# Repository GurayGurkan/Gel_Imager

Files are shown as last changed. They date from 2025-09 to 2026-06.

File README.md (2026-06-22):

# Open Science Multi-function Gel Imager
*An Open-Hardware Agorose Gel and Chemiluminicance Imaging System Based on Raspberry Pi 4B*

This repository involves:
  - **Mechanical Design Files**: FreeCAD drawingshousing of Incu-stream mechanical parts
  - **Electronics**: Circuit schematics and PCB layout files of Raspberrry Pi 4B shield and led control electronics.
  - **Software**: Involves Python codes for main control and user interface. 
  -

For suggestions and questions, please e-mail to ***guraygurkan@istanbul.edu.tr***

Cheers!

Guray Gurkan

* **Please cite this repo as:** 

(Under Review: submitted to Scientific Reports for review)

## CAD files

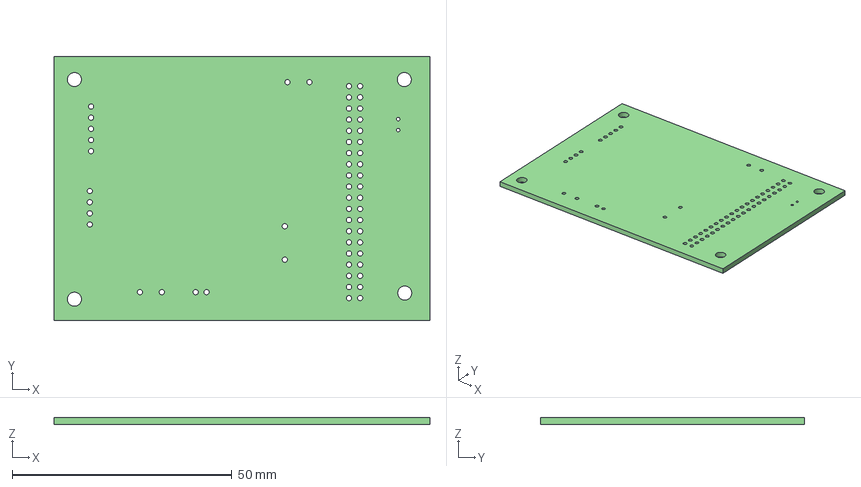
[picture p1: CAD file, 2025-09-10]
Hardware/Electronics/RaspShiled_ver3/RaspShiled_ver3.step
85.6 x 60.0 x 1.60 mm

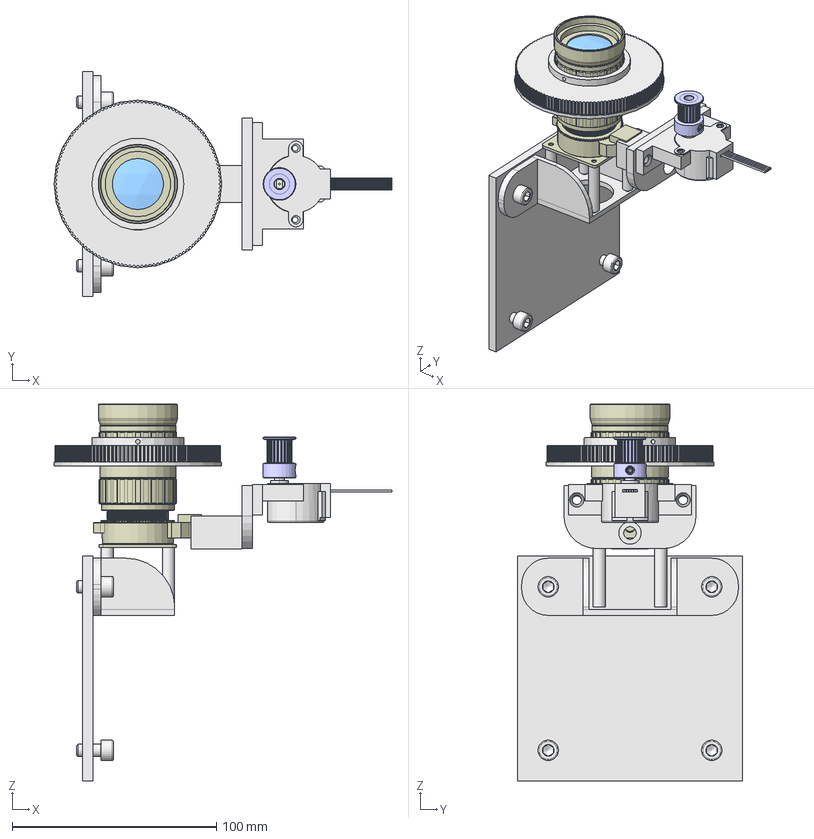
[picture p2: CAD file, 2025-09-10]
Hardware/Mechanical_Designs/Lens_Focus_Control_Design.FCStd
165.2 x 110.0 x 184.4 mm
PICAM HQ
PICAM HQ LENS
Motor
M4x0.7X5mm - flat-tip Set screw
M4x0.7X5mm - flat-tip Set screw001
SystemBracket
LensGear_128
_8byj_48_bracket001 (Solid)001
Distances
_DIN 912-M6x12
_DIN 912-M6x013
_DIN 912-M6x014
_DIN 912-M6x015

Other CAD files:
Hardware/Mechanical_Designs/CNC_Cut_Layer_Designs.FCStd

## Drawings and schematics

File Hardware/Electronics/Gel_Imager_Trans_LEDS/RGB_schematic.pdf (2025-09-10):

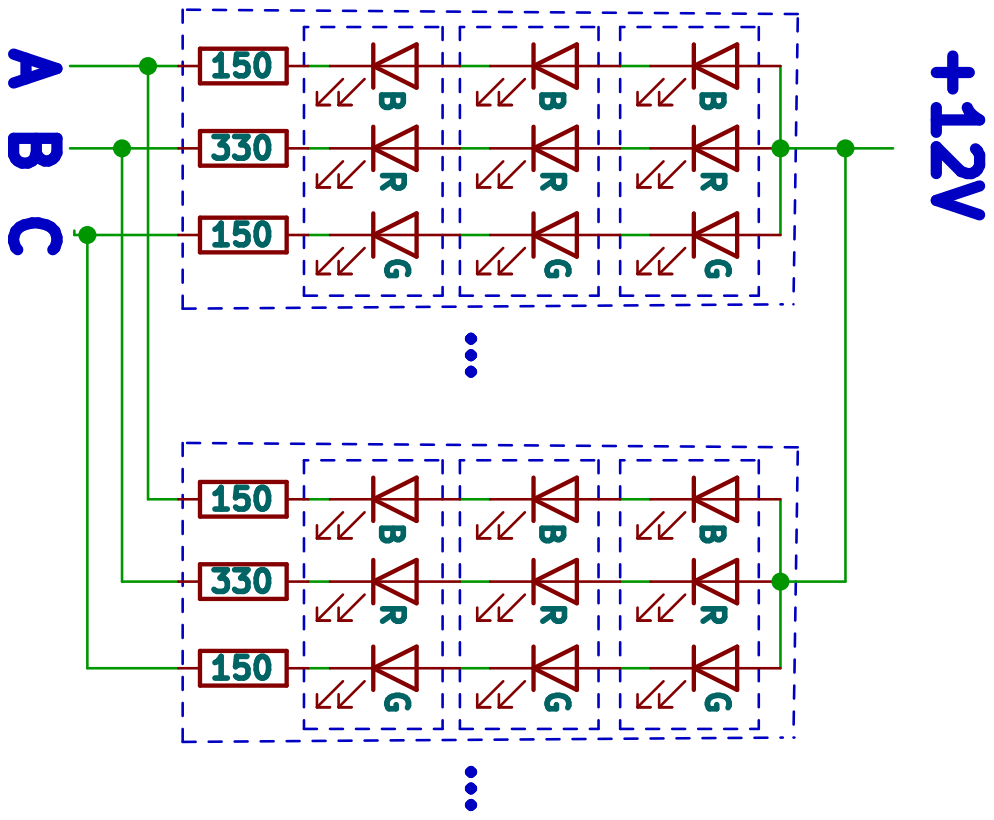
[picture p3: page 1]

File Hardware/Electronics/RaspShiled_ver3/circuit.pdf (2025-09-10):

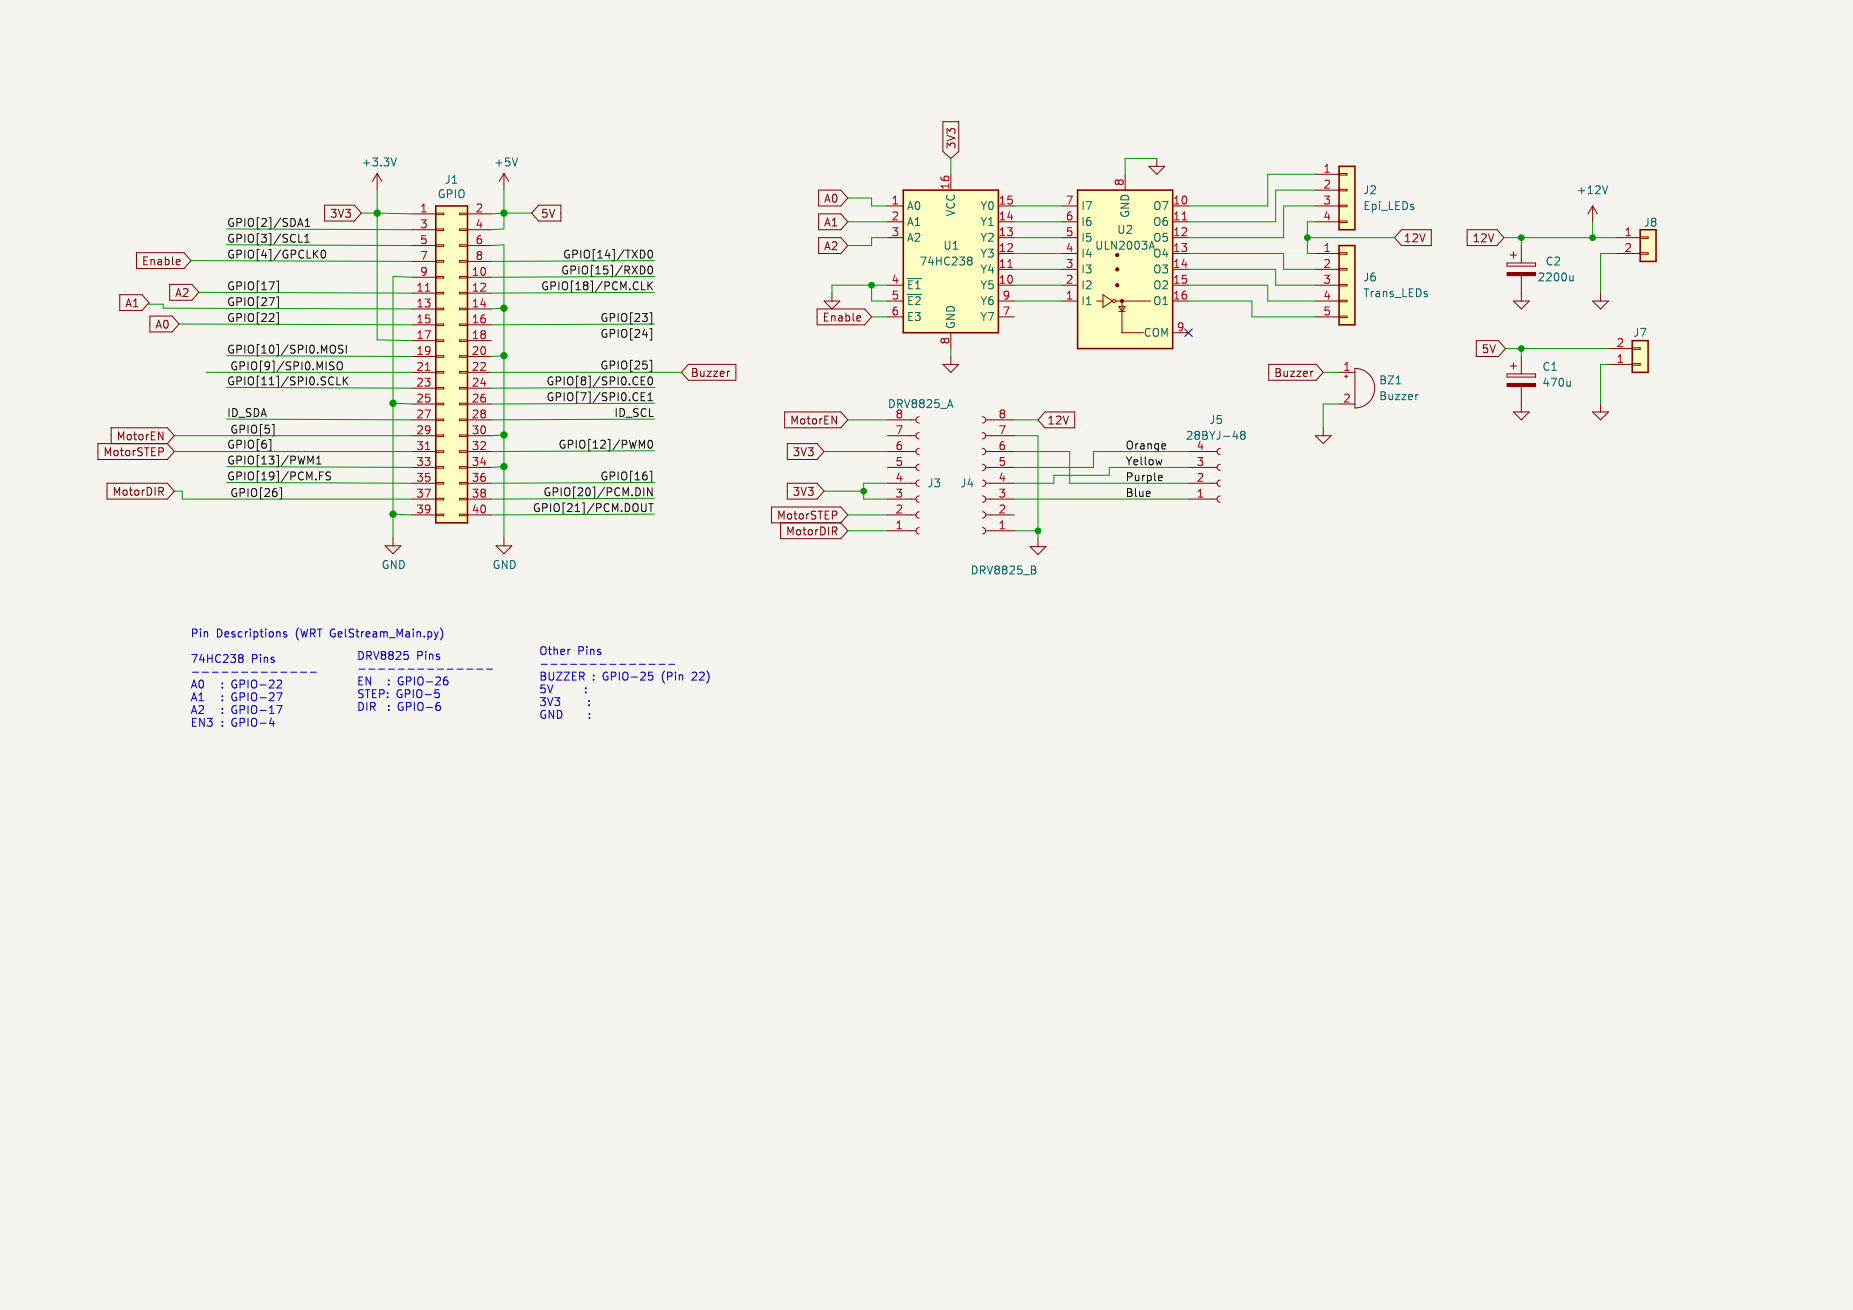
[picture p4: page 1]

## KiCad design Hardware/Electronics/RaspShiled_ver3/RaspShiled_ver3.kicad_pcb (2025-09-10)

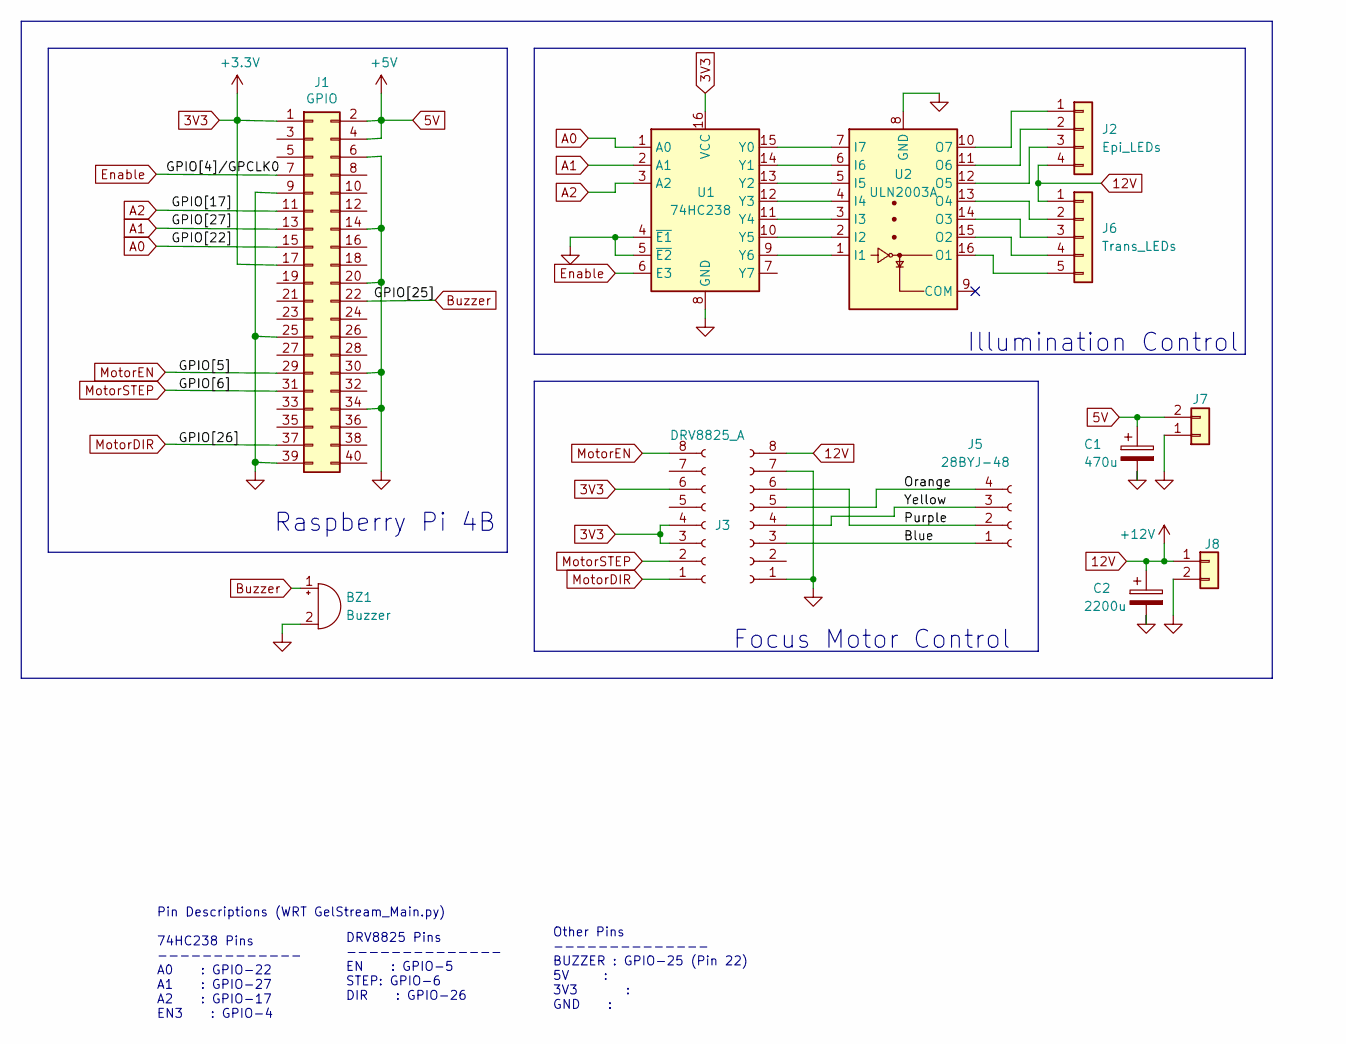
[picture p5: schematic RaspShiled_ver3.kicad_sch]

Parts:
BZ1: Buzzer; Buzzer_12x9.5RM7.6
C1: 470u; CP_Radial_D6.3mm_P2.50mm
C2: 2200u; CP_Radial_D6.3mm_P2.50mm
J1: GPIO; PinHeader_2x20_P2.54mm_Vertical
J2: Epi_LEDs; PinHeader_1x04_P2.54mm_Vertical
J3: DRV8825_A; PinSocket_1x08_P2.54mm_Vertical
J4: DRV8825_B; PinSocket_1x08_P2.54mm_Vertical
J5: 28BYJ-48; PinHeader_1x05_P2.54mm_Vertical
J6: Trans_LEDs; PinHeader_1x05_P2.54mm_Vertical
J7, J8: Conn_01x02; TerminalBlock_MetzConnect_Type011_RT05502HBWC_1x02_P5.00mm_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
U1: 74HC238; SOIC-16_3.9x9.9mm_P1.27mm
U2: ULN2003A; DIP-16_W7.62mm

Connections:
3V3: J1.1, J1.17, J3.3, J3.4, J3.6, U1.16 (VCC)
5V: C1.1, J1.2, J1.4, J7.2
12V: C2.1, J2.4, J4.8, J6.1, J8.1
/Blue: J4.3, J5.1
/GPIO[2]/SDA1: J1.3
/GPIO[3]/SCL1: J1.5
/GPIO[7]/SPI0.CE1: J1.26
/GPIO[8]/SPI0.CE0: J1.24
/GPIO[9]/SPI0.MISO: J1.21
/GPIO[10]/SPI0.MOSI: J1.19
/GPIO[11]/SPI0.SCLK: J1.23
/GPIO[12]/PWM0: J1.32
/GPIO[13]/PWM1: J1.33
/GPIO[14]/TXD0: J1.8
/GPIO[15]/RXD0: J1.10
/GPIO[16]: J1.36
/GPIO[18]/PCM.CLK: J1.12
/GPIO[19]/PCM.FS: J1.35
/GPIO[20]/PCM.DIN: J1.38
/GPIO[21]/PCM.DOUT: J1.40
/GPIO[23]: J1.16
/ID_SCL: J1.28
/ID_SDA: J1.27
/Orange: J4.5, J5.4
/Purple: J4.6, J5.2
/Yellow: J4.4, J5.3
A0: J1.15, U1.1 (A0)
A1: J1.13, U1.2 (A1)
A2: J1.11, U1.3 (A2)
Buzzer: BZ1.1 (-), J1.22
Enable: J1.7, U1.6 (E3)
Epi_Blue_EN: U1.15 (Y0), U2.7 (I7)
Epi_Green_EN: U1.13 (Y2), U2.5 (I5)
Epi_Red_EN: U1.14 (Y1), U2.6 (I6)
GND: BZ1.2 (+), C1.2, C2.2, J1.6, J1.9, J1.14, J1.20, J1.25, J1.30, J1.34, J1.39, J4.1, J4.7, J7.1, J8.2, U1.4 (~E1), U1.5 (~E2), U1.8 (GND), U2.8 (GND)
MotorDIR: J1.37, J3.1
MotorEN: J1.29, J3.8
MotorSTEP: J1.31, J3.2
unnamed: J2.1, U2.10 (O7)
unnamed: J2.2, U2.11 (O6)
unnamed: J2.3, U2.12 (O5)
unnamed: J6.2, U2.13 (O4)
unnamed: J6.3, U2.14 (O3)
unnamed: J6.4, U2.15 (O2)
unnamed: J6.5, U2.16 (O1)
Trans_Blue_EN: U1.12 (Y3), U2.4 (I4)
Trans_Green_EN: U1.10 (Y5), U2.2 (I2)
Trans_Red_EN: U1.11 (Y4), U2.3 (I3)
Trans_UV_EN: U1.9 (Y6), U2.1 (I1)

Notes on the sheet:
DRV8825 Pins -------------- EN : GPIO-5 STEP: GPIO-6 DIR : GPIO-26
Illumination Control
Raspberry Pi 4B
Other Pins -------------- BUZZER : GPIO-25 (Pin 22) 5V : 3V3 : GND :
Focus Motor Control
Pin Descriptions (WRT GelStream_Main.py) 74HC238 Pins ------------- A0 : GPIO-22 A1 : GPIO-27 A2 : GPIO-17 EN3 : GPIO-4

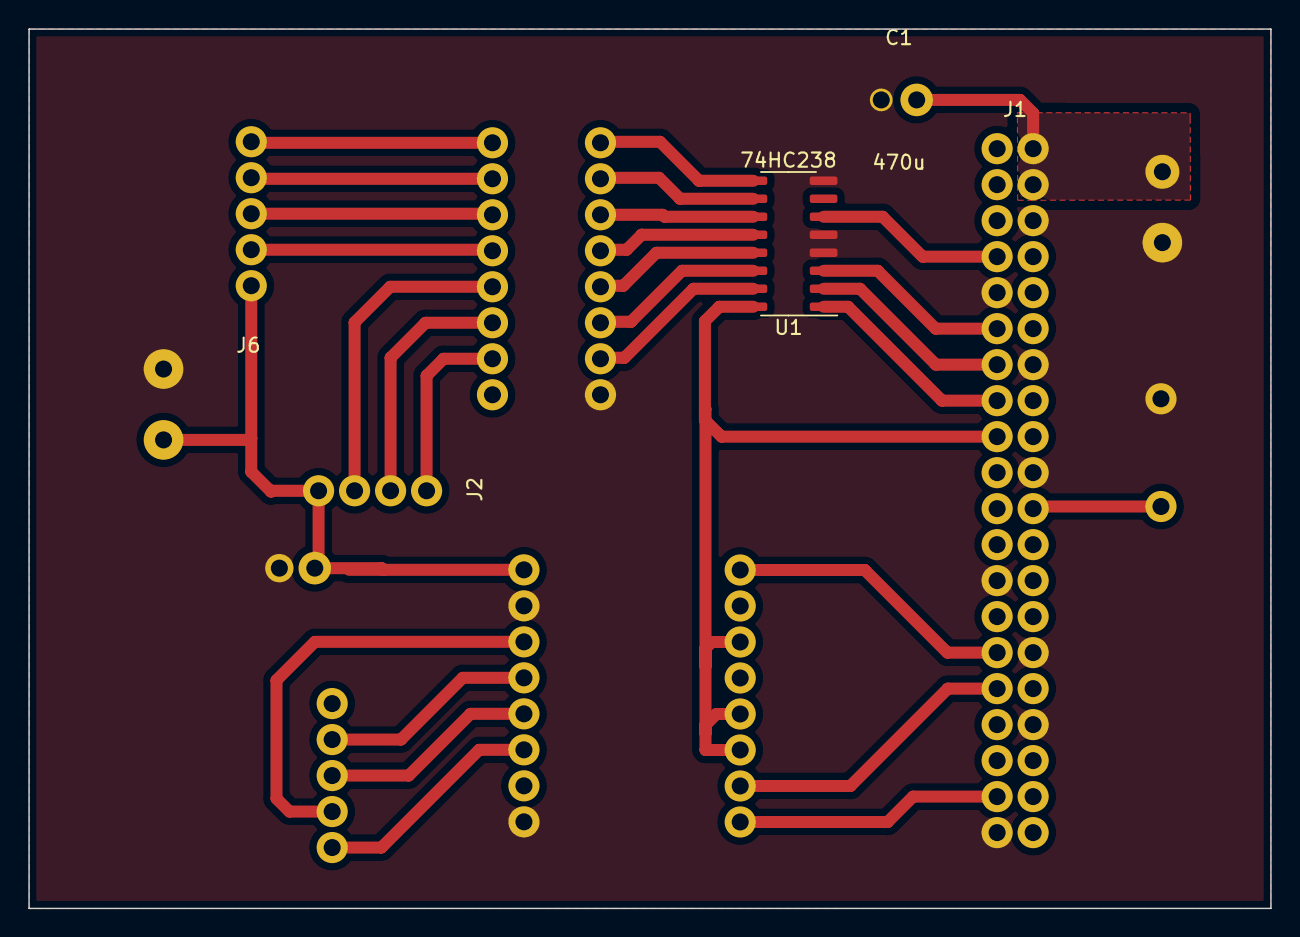
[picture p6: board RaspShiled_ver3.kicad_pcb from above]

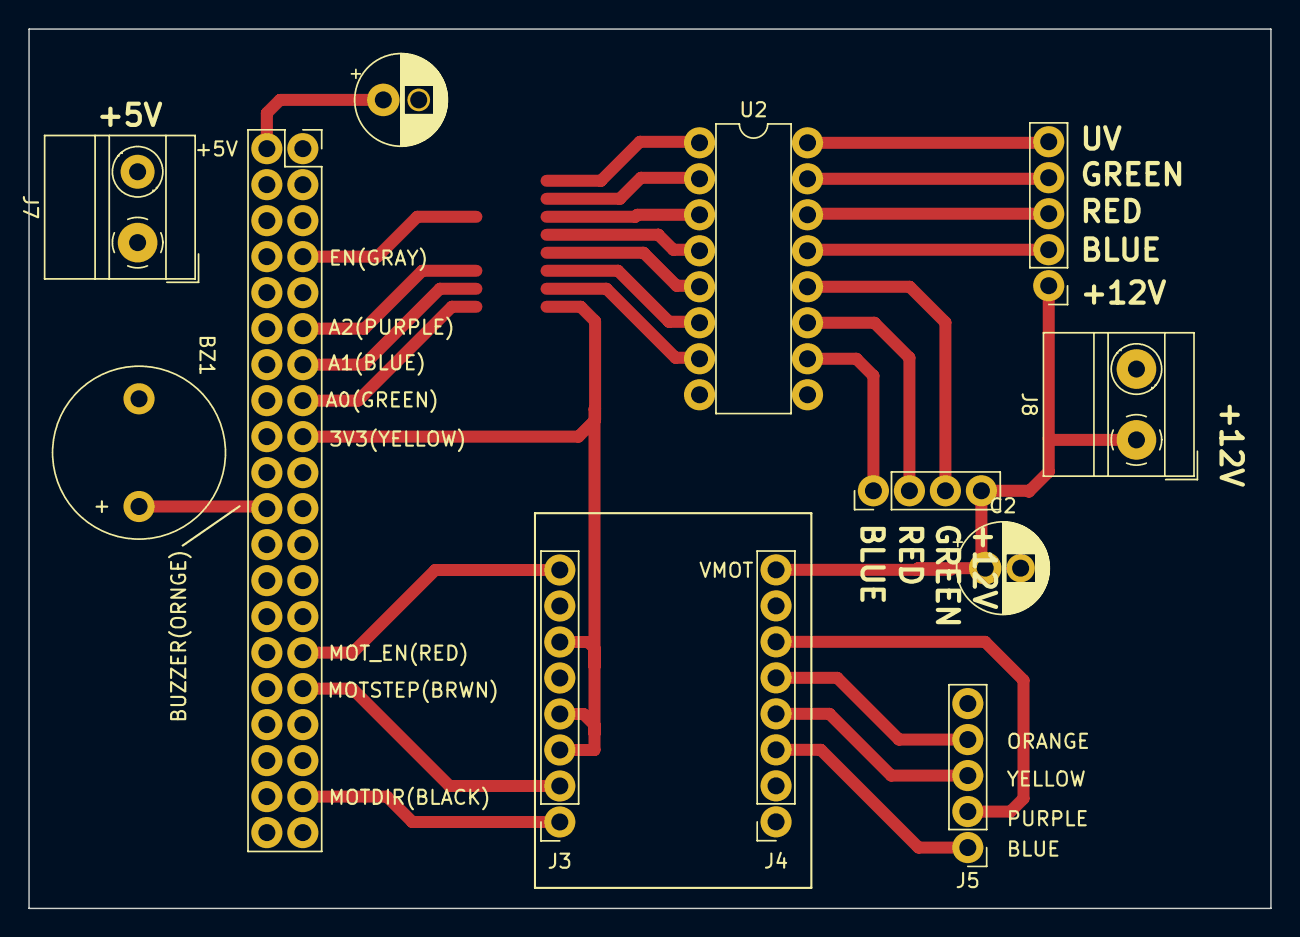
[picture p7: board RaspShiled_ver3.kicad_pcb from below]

Board: 2 copper layers, 87.6 x 62.0 mm, 13 parts (12 on the bottom side), 30 nets.

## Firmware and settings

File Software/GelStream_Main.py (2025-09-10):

from PyQt5 import QtWidgets, uic
from PyQt5.QtWidgets import QDialog, QScroller, QWidget,QMessageBox, QFileDialog, QScrollArea, QLabel, QSizePolicy, QMainWindow, QMenu, QAction, qApp
from PyQt5.QtGui import QImage, QPixmap, QPalette, QPainter, QColor
from PyQt5.QtCore import Qt,QSize, QTimer

import time
import numpy as np
from PIL import Image,ImageDraw,ImageFont, ImageChops

import cv2

import sys
import os
import RPi.GPIO as gp
import picamera2
from picamera2.previews.qt import QGlPicamera2
from picamera2 import Picamera2, Preview
from libcamera import Transform, controls
import configparser
from datetime import datetime as dt
import datetime
#import matplotlib.pyplot as plt

class Ui(QMainWindow):
    COUNT_ENABLE = False
    
    def __init__(self):
        super(Ui, self).__init__()
        uic.loadUi('GelStream_v8.ui', self)
        # self.setFixedSize(QSize(1024,600))
        # self.setWindowFlags( Qt.CustomizeWindowHint )
        # self.setWindowFlags( Qt.WindowMaximizeButtonHint) 
        self.preview = False
        self.previewW = 676
        self.previewH = 507
        self.sensorFH = 3040
        self.sensorFW = 4056
        self.exposureScaler = 1 #ms
        self.LightMode=["None",""]
        
        

        self.captureDialog = QMessageBox()
        self.captureDialog.setMinimumWidth(500)
        self.captureDialog.setText("Capturing...")
        self.captureDialog.setStandardButtons = QMessageBox.Cancel
        self.timerBackcount = QTimer()
        self.timerBackcount.timeout.connect(self.print_time_left)

        self.saveFolder = ""
        
        
        #tune = Picamera2.load_tuning_file("imx477_noir.json")
        #self.picam2 = Picamera2(tuning=tune)
        
        self.picam2 = Picamera2()

        #self.cfg_preview = self.picam2.create_preview_configuration(display="main",buffer_count = 2, main={'format': 'XBGR8888','size':(4056,3040)},controls={"AeEnable":False,"AwbEnable":True,"ColourGains":[1,1]})
        self.cfg_preview = self.picam2.create_preview_configuration(display="main",buffer_count = 2, main={'format': 'XBGR8888','size':(4056,3040)},controls={"AeEnable":False,"AwbEnable":True})
        #self.cfg_preview = self.picam2.create_preview_configuration(display="main",controls={"AeEnable":False,"AwbEnable":False,"ColourGains":[2,2]})
        self.cfg_capture = self.picam2.create_still_configuration(buffer_count = 1,raw={'format':'SRGGB12_CSI2P','size':(4056,3040)}) #controls={"AeEnable":False,"AwbEnable":False,"ColourGains":[2,2]})
        
        #self.cfg_capture = self.picam2.create_still_configuration(raw={'format': 'SBGGR12', 'size': (4056,3040)})
        #picam2.create_still_configuration(raw={'format': mode['unpacked']}, sensor={'output_size': mode['size'], 'bit_depth': mode['bit_depth']})
        print(self.cfg_preview)
        print(self.cfg_capture)
        
        self.picam2.options["quality"] = 95
        self.picam2.options["compress_level"] = 0
        
        self.picam2.set_controls({"AeEnable":False,"AwbEnable":False,"ColourGains": [2,2]})
        self.picam2.set_controls({"NoiseReductionMode":controls.draft.NoiseReductionModeEnum.Off})
        self.picam2.configure(self.cfg_preview)
        
        self.qpicamera2 = QGlPicamera2(self.picam2, width=self.sensorFW, height=self.sensorFH, keep_ar=True)
        
        self.qpicamera2.done_signal.connect(self.capture_done)
        self.qpicamera2.setBackgroundRole(QPalette.Base)
        #self.qpicamera2.setSizePolicy(QSizePolicy.Fixed, QSizePolicy.Fixed)
        # self.qpicamera2.setSizePolicy(QSizePolicy.Ignored, QSizePolicy.Ignored)
        
        
        # overlay1 = 64.*np.ones((507, 700, 4))
        # overlayFile= cv2.imread("overlay.png")
        # overlay1[:,:,:3] = overlayFile

        # self.qpicamera2.set_overlay(overlay1.astype('uint8'))

        #self.scrollPreview.setBackgroundRole(QPalette.Dark)
        self.scrollPreview.setWidget(self.qpicamera2)
        self.scrollPreview.setVisible(False)
        self.scrollPreview.setWidgetResizable(False)
        
        
        
        self.imageLabel = QLabel()
        pix = QPixmap(4056,3040)
        pix.fill(QColor(255,255,0,255))
        self.imageLabel.setBackgroundRole(QPalette.Base)
        self.imageLabel.setSizePolicy(QSizePolicy.Ignored, QSizePolicy.Ignored)
        self.imageLabel.setPixmap(pix)
        self.imageLabel.setScaledContents(True)

        
        self.scrollCapture.setBackgroundRole(QPalette.Dark)
        self.scrollCapture.setWidget(self.imageLabel)
        self.scrollCapture.setVisible(False)
        
        self.checkBoxCaptureFit.stateChanged.connect(self.updateCaptureFit)
                    
        self.buttonPreview.clicked.connect(self.handlePreview)
        self.buttonOpenFile.clicked.connect(self.viewFile)
        self.buttonFocusBottom.clicked.connect(self.handleLensUp)
        self.buttonFocusTop.clicked.connect(self.handleLensDown)
        self.buttonFocusBottomFast.clicked.connect(self.handleLensUpFast)
        self.buttonFocusTopFast.clicked.connect(self.handleLensDownFast)
        self.buttonSnap.clicked.connect(self.handleSnapshot)
        self.buttonShutdown.clicked.connect(self.handleQuit)
        
        
        #self.sliderExpo.valueChanged.connect(self.paramExpo)
        self.sliderExpoTime.valueChanged.connect(self.paramExpoTime)
        self.sliderBrightness.valueChanged.connect(self.paramBright)
        self.sliderContrast.valueChanged.connect(self.paramContrast)
        self.sliderGain.valueChanged.connect(self.paramGain)
        self.sliderSatur.valueChanged.connect(self.paramSatur)
        
        #self.checkBoxLR.stateChanged.connect(self.paramLRUD)
        #self.checkBoxUD.stateChanged.connect(self.paramLRUD)
        #self.checkBoxAe.stateChanged.connect(self.paramAe)
        self.checkBoxZoom.stateChanged.connect(self.handleZoom)
        self.groupEpi.toggled.connect(self.handleEpi)
        self.groupTrans.toggled.connect(self.handleTrans)
        self.buttonsEpi.buttonToggled[QtWidgets.QAbstractButton,bool].connect(self.updateEpiLights)
        self.buttonsTrans.buttonToggled[QtWidgets.QAbstractButton,bool].connect(self.updateTransLights)
        
        self.exposureScaleSelect.activated[str].connect(self.updateExposureScale)
	
        gp.setmode(gp.BCM)
        self.pins74238 = ["","","",""] # A0, A1, A2, DATA (ON/OFF)
        # 74238 as 1-to-8 Demux with 3 pins address control, 1 pin data input
        self.pins74238[0] = 22 # pin 15 S0
        self.pins74238[1] = 27 # pin 13 S1
        self.pins74238[2] = 17 # pin 11 S2
        self.pins74238[3] = 4  # pin  7 DATA
        
        
        self.enableDEMUXpins()
        gp.output(self.pins74238[:],0)
        self.DEMUXADDRESS = 0
        self.motorStepPin = 6 #5
        self.motorDirPin = 26 #6
        self.motorEnablePin = 5 #26
        
        self.buzzerPin = 25
        
        gp.setup(self.motorStepPin,gp.OUT)
        gp.setup(self.motorDirPin,gp.OUT)
        gp.setup(self.motorEnablePin,gp.OUT)
        gp.setup(self.buzzerPin,gp.OUT)
        
        gp.output(self.motorEnablePin,1)
        
        #self.settings = configparser.ConfigParser()
        
        self.beep_long()

        QScroller.grabGesture(self.scrollPreview,QScroller.TouchGesture)
        QScroller.grabGesture(self.scrollCapture,QScroller.TouchGesture)
        self.show()
        
        
            
        
        for i in range(1,10):
            self.toolBox.setItemEnabled(i,False)
        

    def handlePreview(self):
        if self.preview:
            self.scrollPreview.setVisible(False)
            self.buttonOpenFile.setEnabled(True)
            self.picam2.stop()
            self.buttonPreview.setText("Start Camera")
            self.buttonShutdown.setEnabled(True)
            self.buttonFocusBottom.setEnabled(False)
            self.buttonFocusTop.setEnabled(False)
            self.buttonSnap.setEnabled(False)
            for i in range(1,10): #Disable pages except Preview and Turn-off
                self.toolBox.setItemEnabled(i,False)
            self.toolBox.setItemEnabled(self.toolBox.indexOf(self.pageTurnoff),True)
            gp.output(self.pins74238[:],0)
        else:
            #self.loadConfig()
            self.picam2.start()
            self.buttonPreview.setText("Stop Camera")
            self.buttonSnap.setEnabled(True)
            self.buttonOpenFile.setEnabled(False)
            self.checkBoxCaptureFit.setEnabled(False)
            self.buttonFocusBottom.setEnabled(True)
            self.buttonFocusTop.setEnabled(True)
            self.toolBox.setItemEnabled(self.toolBox.indexOf(self.pageTurnoff),False)
            self.scrollPreview.setVisible(True)
            self.scrollCapture.setVisible(False)

            for i in range(1,10): #Enable pages
                self.toolBox.setItemEnabled(i,True)
               

        self.preview = not self.preview
    
    
    def viewFile(self):
        options = QFileDialog.Options()
        # fileName = QFileDialog.getOpenFileName(self, "Open File", QDir.currentPath())
        fileName, _ = QFileDialog.getOpenFileName(self, 'QFileDialog.getOpenFileName()', '',
                                                  'Images (*.png *.jpeg *.jpg *.bmp *.gif)', options=options)
        if fileName:
            image = QImage(fileName)
            
            if image.isNull():
                QMessageBox.information(self, "Gel-Stream", "Cannot load %s." % fileName)
                return

            pix =QPixmap.fromImage(image)
            self.imageLabel.setPixmap(pix)
            self.scrollCapture.setVisible(True)
            self.checkBoxCaptureFit.setEnabled(True)
    


    def updateCaptureFit(self,flag):
        state = flag
        if state:
            self.imageLabel.resize(self.scrollCapture.width(),int(self.sensorFH*self.scrollCapture.width()/self.sensorFW))
        else:
            self.imageLabel.resize(self.sensorFW,self.sensorFH)
           
    
    def handleLensUp(self):
        gp.output(self.motorDirPin, 1)
        self.moveStepper(32)
        print("Lens Up")
        
    def handleLensUpFast(self):
        gp.output(self.motorDirPin, 1)
        self.moveStepper(320)
        print("Lens Up Fast")
        
        
    def handleLensDown(self):
        gp.output(self.motorDirPin, 0)
        self.moveStepper(32)   
        print("Lens Down")
        
    def handleLensDownFast(self):
        gp.output(self.motorDirPin, 0)
        self.moveStepper(320)   
        print("Lens Down Fast")
        
    # def paramLRUD(self):
        # if self.checkBoxLR.isChecked():
            # flagLR=1
        # else:
            # flagLR=0
                
        # if self.checkBoxUD.isChecked():
            # flagUD=1
        # else:
            # flagUD=0
        # if self.preview:
            # self.picam2.stop()
        # self.cfg_preview = self.picam2.create_preview_configuration(display="main",main={'format': 'XBGR8888','size':(4056,3040)},controls={"AeEnable":False,"AwbEnable":False,"ColourGains":[2,2]},transform=Transform(vflip=flagUD,hflip=flagLR))
        # self.cfg_capture = self.picam2.create_still_configuration(raw=self.picam2.sensor_modes[3],transform=Transform(vflip=flagUD,hflip=flagLR))
        # self.picam2.configure(self.cfg_preview)
        # #self.cfg_preview = self.picam2.create_preview_configuration(transform=Transform(vflip=flagUD,hflip=flagLR))
        # #self.cfg_capture = self.picam2.create_still_configuration(transform=Transform(vflip=flagUD,hflip=flagLR))
        # if self.preview:
            # self.picam2.start()
        
        
    def handleSnapshot(self):
        if self.preview:
            response = QFileDialog.getExistingDirectory(self,caption="Select Folder:")
            if response !="":
                self.saveFolder = response
                print(response)
                
                self.acqtime = time.localtime()
                
                #fname = 'GI_{}_{}_{}_{}_{}_{}'.format(tt[0],tt[1],tt[2],tt[3],tt[4],tt[5])
                for i in range(10): 
                    self.toolBox.setItemEnabled(i,False)
                self.buttonSnap.setEnabled(False)
                self.channelChoice.setEnabled(False)
                self.statusbar.showMessage("Saving Image File...")
                
                self.captureDialog.show()
                
                
                #self.picam2.switch_mode(self.cfg_capture)
                
                #job=self.picam2.capture_array(name="raw",signal_function = self.qpicamera2.signal_done)
                print("starting job")

                if self.COUNT_ENABLE:
                    self.timerBackcount.start(1000)
                
                
                job = self.picam2.switch_mode_and_capture_array( self.cfg_capture,signal_function = self.qpicamera2.signal_done)
                self.cycle_on = time.time()
                
                
                
                
            
    
    def capture_done(self,job):
        
        print("Inside capture_done()")
        self.statusbar.showMessage("Saving Image File...Done")
        data = self.picam2.wait(job)
        
        self.timerBackcount.stop()
        
        print(data.shape)
        tt = self.acqtime
        fname = 'GI_{}_{}_{}_{}_{}_{}_'.format(tt[0],tt[1],tt[2],tt[3],tt[4],tt[5])
        filter_option = self.channelChoice.currentText()
        print(filter_option)
        if (filter_option=="BLUE"):
            img = Image.fromarray(data[:,:,2],'P')
        elif (filter_option=="GREEN"):
            img = Image.fromarray(data[:,:,1],'P')
        elif (filter_option=="RED"):
            img = Image.fromarray(data[:,:,0],'P')
        inverted = False  
        if self.checkBoxInvertedSave.isChecked():
            img = ImageChops.invert(img)
            print("Donnnne")
            inverted = True
      
        #img=img.rotate(90,expand=True)    
        self.put_parameters(img,(65,65),50,inverted)
        img.save(self.saveFolder + "/" + fname+ str(filter_option) + ".png")
        
        
        for i in range(10):
            self.toolBox.setItemEnabled(i,True)
        self.buttonSnap.setEnabled(True)
        self.channelChoice.setEnabled(True)
        self.beep_long()
        self.captureDialog.close()
        
        QMessageBox.information(self,"GelStream","Capture Complete!")
        
        
    def put_parameters(self,img,position,font_size,inverted_flag):
        if inverted_flag:
            bwcolor=0
        else:
            bwcolor=255
                
        font = ImageFont.truetype("/usr/share/fonts/truetype/freefont/FreeSansBold.ttf", font_size)
        exposure =  str(self.sliderExpoTime.value())
        exp_units =self.exposureScaleSelect.currentText()
        gain= str(self.sliderGain.value())
        brightness = str(self.sliderBrightness.value()/8.)
        contrast= str(self.sliderContrast.value())
        saturation= str(self.sliderSatur.value()/8.)
        I1 = ImageDraw.Draw(img)
        x0 = position[0]
        y0 = position[1]
        I1.text((x0,y0+0*font_size), "Gel-Stream v1.0",(bwcolor),font=font)
        I1.text((x0,y0+1*font_size), "Channel: " + self.channelChoice.currentText(),(bwcolor),font=font)
        I1.text((x0,y0+2*font_size ), "Exposure: " + exposure + " " + exp_units,(bwcolor),font=font)
        I1.text((x0,y0+3*font_size), "Gain: " + gain,(bwcolor),font=font)
        I1.text((x0,y0+4*font_size), "Brightness: " + brightness,(bwcolor),font=font)
        I1.text((x0,y0+5*font_size), "Contrast: " + contrast,(bwcolor),font=font)
        I1.text((x0,y0+6*font_size), "Saturation: " + saturation,(bwcolor),font=font)
        I1.text((x0,y0+7*font_size), "Illumination Mode: " + self.LightMode[0] + self.LightMode[1],(bwcolor),font=font)
        I1.text((x0,y0+8*font_size), "Emission Filter: " + self.emissionFilter.currentText(),(bwcolor),font=font)
        
        
    def moveStepper(self, steps):
        gp.output(self.motorEnablePin,0)
        self.beep_short()
        for i in range(steps):
            time.sleep(0.001)
            gp.output(self.motorStepPin,0)
            time.sleep(0.001)
            gp.output(self.motorStepPin,1)
        
           
        # send pulses to "motorStepPin" pin
        
        gp.output(self.motorEnablePin,1)
            
    
    """   
    def paramExpo(self,val):
        self.picam2.controls.ExposureValue=val
        self.valExpo.setText(str(val))
        self.statusbar.showMessage("Setting exposure to " + str(val))
    """    
    def paramExpoTime(self,val):
        self.picam2.controls.ExposureTime = int(val*self.exposureScaler)
        self.updateExposureScale(self.exposureScaleSelect.currentText())
        self.valExpoTime.setText(str(val) + " " + self.exposureScaleSelect.currentText())
        self.statusbar.showMessage("Setting exposure time to " + str(val) + " " + self.exposureScaleSelect.currentText())
    
    def updateExposureScale(self,text):
        if text =="minutes":
            self.exposureScaler = 1E06*60
            self.sliderExpoTime.setMaximum(10)
            self.COUNT_START = dt(1900,1,1,0,int(self.sliderExpoTime.value()),0)
            self.COUNT_ENABLE = True
        
        elif text =="seconds":
            self.exposureScaler = 1E06
            self.sliderExpoTime.setMaximum(59)
            if self.sliderExpoTime.value()<60:
                self.COUNT_START = dt(1900,1,1,0,0,int(self.sliderExpoTime.value()))
                self.COUNT_ENABLE = True
        
        elif text =="ms":
            self.exposureScaler = 1E03
            self.sliderExpoTime.setMaximum(1000)
            self.COUNT_ENABLE = False
        
        elif text=="microseconds":
            self.exposureScaler = 1
            self.sliderExpoTime.setMaximum(5000)
            self.COUNT_ENABLE = False
            
    def print_time_left(self):
        
        self.captureDialog.setText("Time left: " + str(dt.strftime( self.COUNT_START + datetime.timedelta(seconds = -round(time.time()-self.cycle_on)+1),"%M:%S")))
        self.captureDialog.repaint()
           
    def paramBright(self,val):
        self.picam2.controls.Brightness=val/8.
        self.valBright.setText(str(val/8.))
        self.statusbar.showMessage("Setting brightness to " + str(val/8.))
    
    def paramContrast(self,val):
        self.picam2.controls.Contrast=val
        self.valContrast.setText(str(val))
        self.statusbar.showMessage("Setting contrast to " + str(val))
    def paramGain(self,val):
        self.picam2.controls.AnalogueGain=val
        self.valGain.setText(str(val))
        self.statusbar.showMessage("Setting Gain to " + str(val))
    def paramSatur(self,val):
        self.picam2.controls.Saturation = val/8.
        self.valSatur.setText(str(val/8.))
        self.statusbar.showMessage("Setting Saturation to " + str(val/8.))
        
    def paramAe(self):
        flag = self.checkBoxAe.isChecked()
        self.picam2.controls.AeEnable = flag
        if flag:
            self.statusbar.showMessage("AutoExposure Enabled.")
        else:
            self.statusbar.showMessage("AutoExposure Disabled.")
        
        
            
    def handleZoom(self):
        flag = self.checkBoxZoom.isChecked()
        print(flag)
        if flag:
            self.qpicamera2.setFixedWidth(self.scrollPreview.width()-10)
            self.qpicamera2.setFixedHeight(self.scrollPreview.height()-10)
            print(self.scrollPreview.horizontalScrollBar().pageStep())
            
        else:
            
            self.qpicamera2.setFixedWidth(self.sensorFW)
            self.qpicamera2.setFixedHeight(self.sensorFH)
            
            self.scrollPreview.verticalScrollBar().setValue(3040/2)
            self.scrollPreview.horizontalScrollBar().setValue(2028-400)
            #print("VertScroll:",self.scrollPreview.verticalScrollBar().value())

    def handleEpi(self):
        if self.groupEpi.isChecked():
            self.LightMode=['Epi-',""]
            self.groupTrans.setChecked(False)
            self.updateDEMUXaddress(self.DEMUXADDRESS)
            self.enableDEMUXoutput(True)
            
        else:
            self.LightMode=['Trans-',""]
            self.enableDEMUXoutput(False)
            
    def handleTrans(self):
        if self.groupTrans.isChecked():
            self.LightMode=['Trans-',""] 
            self.groupEpi.setChecked(False)
            self.updateDEMUXaddress(self.DEMUXADDRESS)
            self.enableDEMUXoutput(True)
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
